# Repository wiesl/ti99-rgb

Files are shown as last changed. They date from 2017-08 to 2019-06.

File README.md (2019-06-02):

TMS9929A RGB Converter
======================

This RGB converter is based on this great project:
[TMS9929A RGB and Component adapter - A high resolution Component, RGB or SCART adapter for MSX and Colecovision](https://hackaday.io/project/13056-tms9929a-rgb-and-component-adapter).

It converts signals from a TMS9929 with correct colors to RGB.

See also this [thread](https://www.classic-computers.org.nz/forums/viewtopic.php?f=11&t=960) for more information.

Authors
=======

Original author: Copyright 2016: Alexis Kotlowy <256byteram@gmail.com>

Enhanced version: Copyright 2017: Gerhard Wiesinger <ti99@wiesinger.com>

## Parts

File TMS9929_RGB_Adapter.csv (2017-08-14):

Reference | Value | Footprint | Datasheet
U2 | XR8052 | SMD_Packages:SOIC-8-N
U3 | XR8052 | SMD_Packages:SOIC-8-N
R11 | 1k | Resistors_SMD:R_0805_HandSoldering
R14 | 2k | Resistors_SMD:R_0805_HandSoldering
R13 | 3.6k | Resistors_SMD:R_0805_HandSoldering
R22 | 1k | Resistors_SMD:R_0805_HandSoldering
R19 | 1k | Resistors_SMD:R_0805_HandSoldering
R20 | 1k | Resistors_SMD:R_0805_HandSoldering
R21 | 2k | Resistors_SMD:R_0805_HandSoldering
U1 | XR8052 | SMD_Packages:SOIC-8-N
R4 | 1k | Resistors_SMD:R_0805_HandSoldering
R6 | 2k | Resistors_SMD:R_0805_HandSoldering
R5 | 1.2k | Resistors_SMD:R_0805_HandSoldering
R7 | 1k | Resistors_SMD:R_0805_HandSoldering
R3 | 1k | Resistors_SMD:R_0805_HandSoldering
R1 | 1.2k | Resistors_SMD:R_0805_HandSoldering
R12 | 6.2k | Resistors_SMD:R_0805_HandSoldering
R15 | 9.1k | Resistors_SMD:R_0805_HandSoldering
R18 | 1k | Resistors_SMD:R_0805_HandSoldering
R16 | 1k | Resistors_SMD:R_0805_HandSoldering
R8 | 1k | Resistors_SMD:R_0805_HandSoldering
R10 | 1k | Resistors_SMD:R_0805_HandSoldering
R2 | 75R | Resistors_SMD:R_0805_HandSoldering
R9 | 75R | Resistors_SMD:R_0805_HandSoldering
R17 | 75R | Resistors_SMD:R_0805_HandSoldering
C3 | 47uF | Capacitors_Tantalum_SMD:TantalC_SizeB_EIA-3528_HandSoldering
C2 | 47uF | Capacitors_Tantalum_SMD:TantalC_SizeB_EIA-3528_HandSoldering
C1 | 47uF | Capacitors_Tantalum_SMD:TantalC_SizeB_EIA-3528_HandSoldering
P1 | CONN_01X06 | Pin_Headers:Pin_Header_Straight_1x06
U4 | 4066 | SMD_Packages:SOIC-14_N
U5 | LM1881 | SMD_Packages:SOIC-8-N
C6 | 100nF | Capacitors_SMD:C_0805_HandSoldering
C7 | 100nF | Capacitors_SMD:C_0805_HandSoldering
R23 | 680k | Resistors_SMD:R_0805_HandSoldering
C8 | 47uF | Capacitors_Tantalum_SMD:TantalC_SizeB_EIA-3528_HandSoldering
C9 | 100nF | Capacitors_SMD:C_0805_HandSoldering
C10 | 100nF | Capacitors_SMD:C_0805_HandSoldering
C11 | 100nF | Capacitors_SMD:C_0805_HandSoldering
C12 | 100nF | Capacitors_SMD:C_0805_HandSoldering
C13 | 100nF | Capacitors_SMD:C_0805_HandSoldering
R24 | 680R | Resistors_SMD:R_0805_HandSoldering
R25 | 82R | Resistors_SMD:R_0805_HandSoldering
P6 | CONN_01X01 | Connect:1pin
P7 | CONN_01X01 | Connect:1pin
P8 | CONN_01X01 | Connect:1pin
P9 | CONN_01X01 | Connect:1pin
P3 | SEL | Pin_Headers:Pin_Header_Straight_1x03
P4 | SEL | Pin_Headers:Pin_Header_Straight_1x03
P5 | SEL | Pin_Headers:Pin_Header_Straight_1x03
U6 | TL081 | SMD_Packages:SOIC-8-N
C14 | 10nF | Capacitors_SMD:C_0805_HandSoldering
C15 | 100nF | Capacitors_SMD:C_0805_HandSoldering
R28 | 10k | Resistors_SMD:R_0805_HandSoldering
R29 | 10k | Resistors_SMD:R_0805_HandSoldering
P2 | CONN_01X08 | Pin_Headers:Pin_Header_Straight_1x08
P10 | 12V | Pin_Headers:Pin_Header_Straight_1x01
R30 | 270R | Resistors_SMD:R_0805_HandSoldering
L1 | FERRITE | Resistors_SMD:R_1206_HandSoldering
R26 | 1k | Resistors_SMD:R_0805_HandSoldering

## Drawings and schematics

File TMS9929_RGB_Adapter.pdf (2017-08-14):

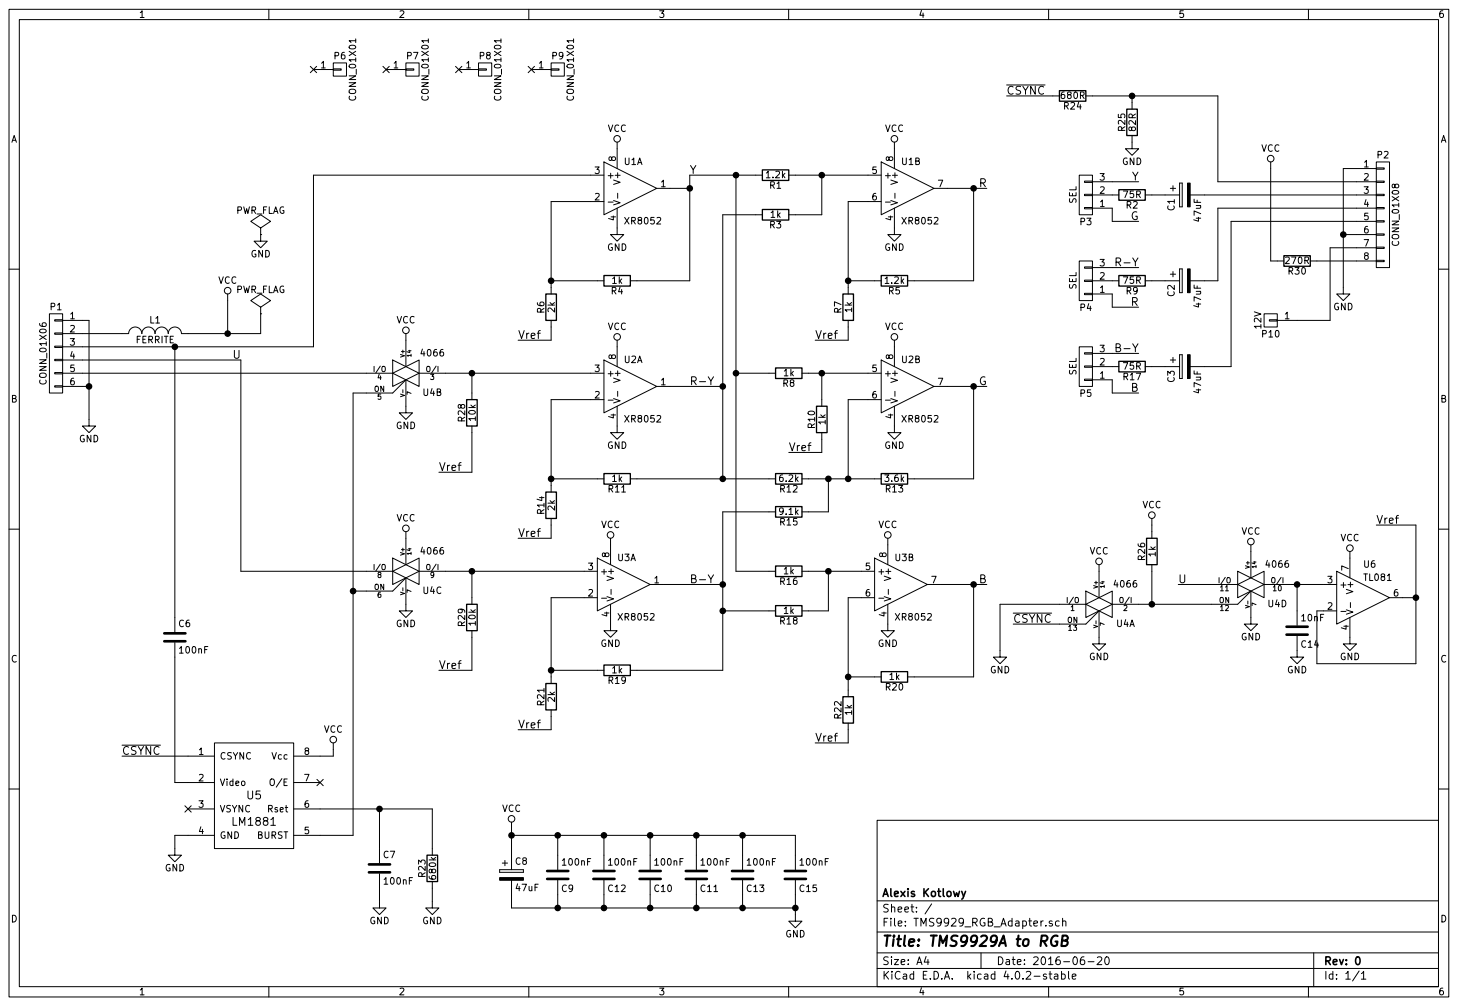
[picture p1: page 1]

Id: 1/1 Title: TMS9929A to RGB

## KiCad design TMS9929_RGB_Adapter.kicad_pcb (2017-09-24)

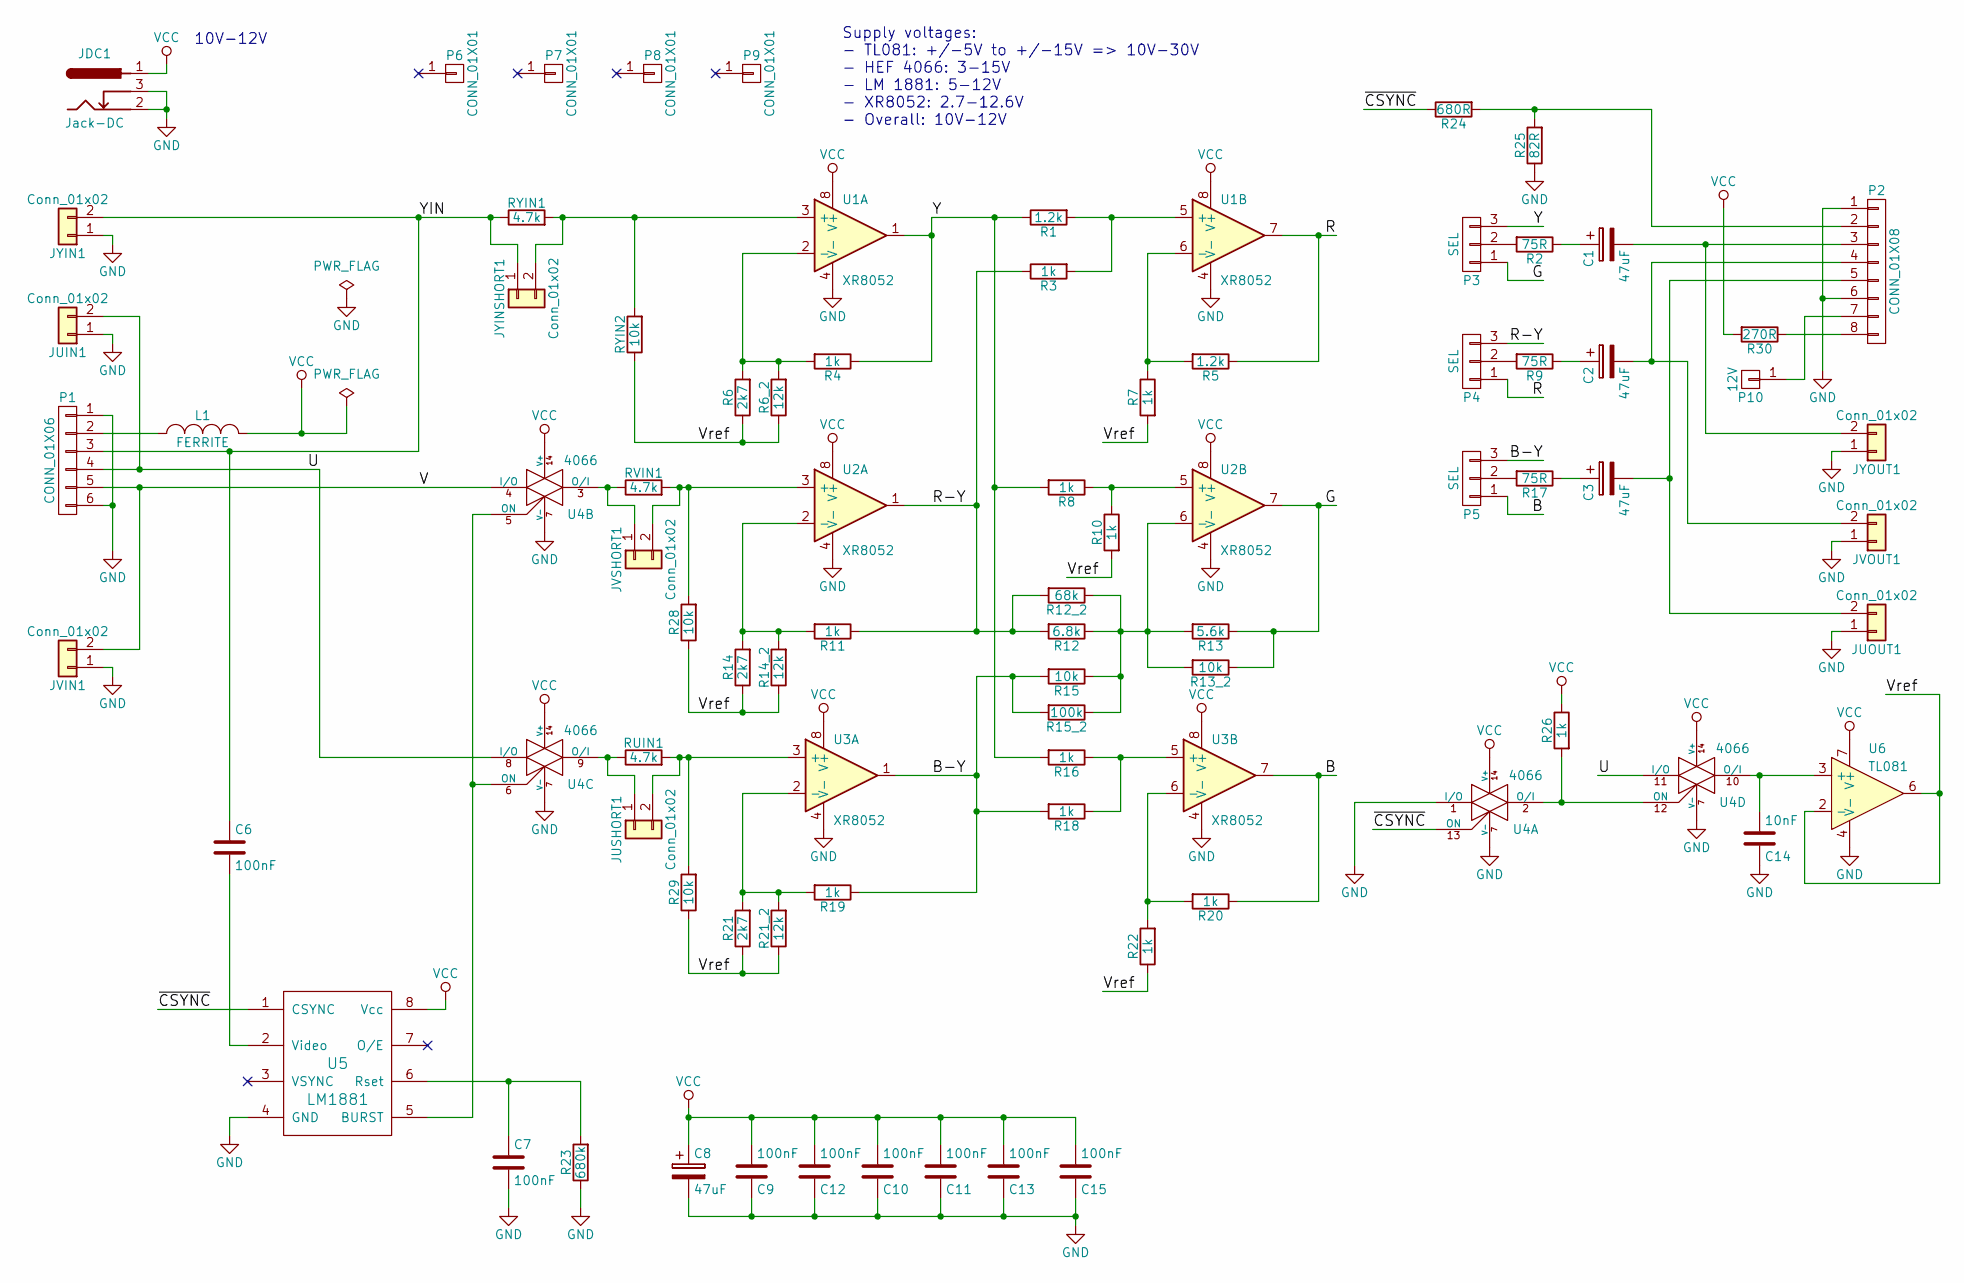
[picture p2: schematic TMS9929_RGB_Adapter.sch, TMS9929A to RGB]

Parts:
C1, C2, C3, C8: 47uF; TantalC_SizeB_EIA-3528_HandSoldering
C6, C7, C9, C10, C11, C12, C13, C15: 100nF; C_0805_HandSoldering
C14: 10nF; C_0805_HandSoldering
JDC1: Jack-DC; jack_2mm
JUIN1: Conn_01x02; rca_white
JUOUT1: Conn_01x02; rca_white
JUSHORT1: Conn_01x02; Pin_Header_Straight_1x02_Pitch2.54mm
JVIN1: Conn_01x02; rca_red
JVOUT1: Conn_01x02; rca_red
JVSHORT1: Conn_01x02; Pin_Header_Straight_1x02_Pitch2.54mm
JYIN1: Conn_01x02; rca_black
JYINSHORT1: Conn_01x02; Pin_Header_Straight_1x02_Pitch2.54mm
JYOUT1: Conn_01x02; rca_black
L1: FERRITE; R_1206_HandSoldering
P1: CONN_01X06; Pin_Header_Straight_1x06_Pitch2.54mm
P2: CONN_01X08; Pin_Header_Straight_1x08_Pitch2.54mm
P3, P4, P5: SEL; Pin_Header_Straight_1x03_Pitch2.54mm
P6, P7, P8, P9: CONN_01X01; 1pin
P10: 12V; Pin_Header_Straight_1x01
R1, R5: 1.2k; R_0805_HandSoldering
R2, R9, R17: 75R; R_0805_HandSoldering
R3, R4, R7, R8, R10, R11, R16, R18, R19, R20, R22, R26: 1k; R_0805_HandSoldering
R6, R14, R21: 2k7; R_0805_HandSoldering
R6_2, R14_2, R21_2: 12k; R_0805_HandSoldering
R12: 6.8k; R_0805_HandSoldering
R12_2: 68k; R_0805_HandSoldering
R13: 5.6k; R_0805_HandSoldering
R13_2, R15, R28, R29: 10k; R_0805_HandSoldering
R15_2: 100k; R_0805_HandSoldering
R23: 680k; R_0805_HandSoldering
R24: 680R; R_0805_HandSoldering
R25: 82R; R_0805_HandSoldering
R30: 270R; R_0805_HandSoldering
RUIN1: 4.7k; R_0805_HandSoldering
RVIN1: 4.7k; R_0805_HandSoldering
RYIN1: 4.7k; R_0805_HandSoldering
RYIN2: 10k; R_0805_HandSoldering
U1, U2, U3: XR8052; SOIC-8-N
U4: 4066; SOIC-14_N
U5: LM1881; SOIC-8-N
U6: TL081; SOIC-8-N

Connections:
/B: P5.1, R20.1, U3.7
/B-Y: P5.3, R15.2, R15_2.2, R18.2, R19.1, U3.1
/G: P3.1, R13.1, R13_2.1, U2.7
/R: P4.1, R5.1, U1.7
/R-Y: P4.3, R3.1, R11.1, R12.2, R12_2.2, U2.1
/U: JUIN1.2, P1.4, U4.8 (I/O), U4.11 (I/O)
/V: JVIN1.2, P1.5, U4.4 (I/O)
/Vref: R6.1, R6_2.1, R7.2, R10.2, R14.1, R14_2.1, R21.1, R21_2.1, R22.1, R28.1, R29.1, RYIN2.1, U6.2 (-), U6.6
/Y: P3.3, R1.1, R4.1, R8.2, R16.2, U1.1
/YIN: C6.1, JYIN1.2, JYINSHORT1.1, P1.3, RYIN1.1
/~CSYNC: R24.1, U4.13 (ON), U5.1 (CSYNC)
GND: C7.2, C8.2, C9.1, C10.1, C11.1, C12.1, C13.1, C14.1, C15.1, JDC1.2, JDC1.3, JUIN1.1, JUOUT1.1, JVIN1.1, JVOUT1.1, JYIN1.1, JYOUT1.1, P1.1, P1.6, P2.1, P2.6, R23.1, R25.1, U1.4 (V-), U2.4 (V-), U3.4 (V-), U4.1 (I/O), U4.7 (V-), U5.4 (GND), U6.4 (V-)
unnamed: C1.1, R2.1
unnamed: C1.2, JYOUT1.2, P2.3
unnamed: C2.1, R9.1
unnamed: C2.2, JVOUT1.2, P2.4
unnamed: C3.1, R17.1
unnamed: C3.2, JUOUT1.2, P2.5
unnamed: C6.2, U5.2 (Video)
unnamed: C7.1, R23.2, U5.6 (Rset)
unnamed: C14.2, U4.10 (O/I), U6.3 (+)
unnamed: JUSHORT1.1, RUIN1.1, U4.9 (O/I)
unnamed: JUSHORT1.2, R29.2, RUIN1.2, U3.3 (+)
unnamed: JVSHORT1.1, RVIN1.1, U4.3 (O/I)
unnamed: JVSHORT1.2, R28.2, RVIN1.2, U2.3 (+)
unnamed: JYINSHORT1.2, RYIN1.2, RYIN2.2, U1.3 (+)
unnamed: L1.1, P1.2
unnamed: P2.2, R24.2, R25.2
unnamed: P2.8, R30.1
unnamed: P3.2, R2.2
unnamed: P4.2, R9.2
unnamed: P5.2, R17.2
unnamed: P2.7, P10.1
unnamed: R1.2, R3.2, U1.5 (+)
unnamed: R4.2, R6.2, R6_2.2, U1.2 (-)
unnamed: R5.2, R7.1, U1.6 (-)
unnamed: R8.1, R10.1, U2.5 (+)
unnamed: R11.2, R14.2, R14_2.2, U2.2 (-)
unnamed: R12.1, R12_2.1, R13.2, R13_2.2, R15.1, R15_2.1, U2.6 (-)
unnamed: R16.1, R18.1, U3.5 (+)
unnamed: R19.2, R21.2, R21_2.2, U3.2 (-)
unnamed: R20.2, R22.2, U3.6 (-)
unnamed: R26.2, U4.2 (O/I), U4.12 (ON)
unnamed: U4.5 (ON), U4.6 (ON), U5.5 (BURST)
VCC: C8.1, C9.2, C10.2, C11.2, C12.2, C13.2, C15.2, JDC1.1, L1.2, R26.1, R30.2, U1.8 (V+), U2.8 (V+), U3.8 (V+), U4.14 (V+), U5.8 (Vcc), U6.7 (V+)

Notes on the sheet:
10V-12V
Supply voltages: - TL081: +/-5V to +/-15V => 10V-30V - HEF 4066: 3-15V - LM 1881: 5-12V - XR8052: 2.7-12.6V - Overall: 10V-12V

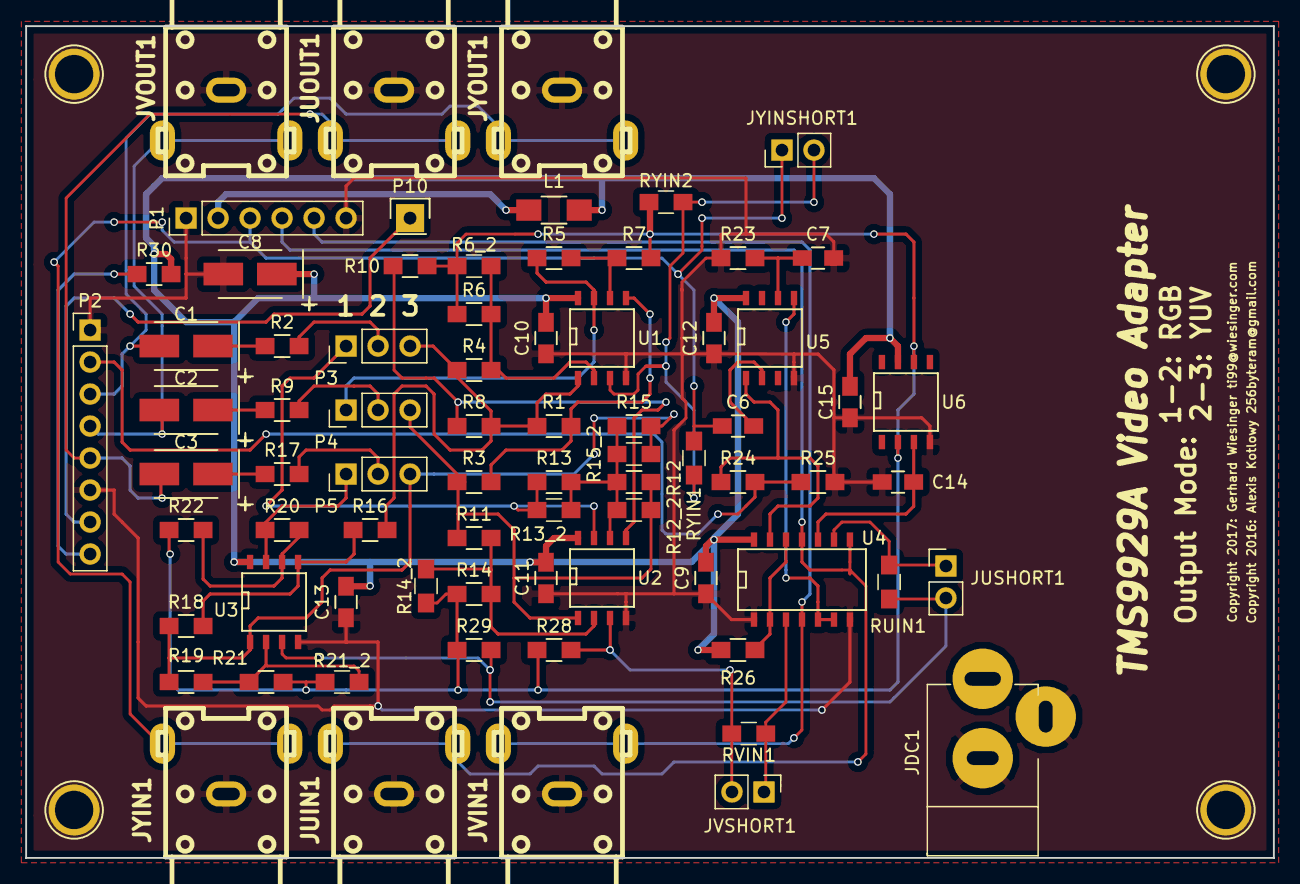
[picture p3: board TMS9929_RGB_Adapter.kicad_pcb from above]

Board: 2 copper layers, 99.1 x 66.0 mm, 79 parts (0 on the bottom side), 45 nets.

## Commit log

2017-08-14 Initial import
    [TMS9929_RGB_Adapter-B.Cu.gbr, TMS9929_RGB_Adapter-B.Mask.gbr, TMS9929_RGB_Adapter-B.SilkS.gbr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]
2017-09-17 Initial changes to new version, copyright, DRC, etc.
    [TMS9929_RGB_Adapter-B.Cu.gbl, TMS9929_RGB_Adapter-B.Cu.gbr, TMS9929_RGB_Adapter-B.Mask.gbr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]
2017-09-17 Updated libraries and removed old drill report file
2017-09-17 Updated schematic & PCB for added Cinch connectors as well as power supply connector and damping resistors/jumpers
    [TMS9929_RGB_Adapter-B.Cu.gbl, TMS9929_RGB_Adapter-B.Mask.gbs, TMS9929_RGB_Adapter-B.SilkS.gbo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]
2017-09-17 Corrected silkscreen with masks (moved it)
    [TMS9929_RGB_Adapter-B.Cu.gbl, TMS9929_RGB_Adapter-B.Mask.gbs, TMS9929_RGB_Adapter-B.SilkS.gbo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]
2017-09-19 Show copper layers
    [TMS9929_RGB_Adapter.kicad_pcb]
2017-09-19 Remove *.drl file
    [TMS9929_RGB_Adapter.drl]
2017-09-19 Smaller PCB cosmetics
    [TMS9929_RGB_Adapter-B.Cu.gbl, TMS9929_RGB_Adapter-B.Mask.gbs, TMS9929_RGB_Adapter-B.SilkS.gbo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]
2017-09-24 schematic: Added comments for power supply, moved capacitor at TL081 (cosmetics)
    [TMS9929_RGB_Adapter.sch]
2017-09-24 Added new resistors in parallel to existing ones to solder standard resistor values
    [TMS9929_RGB_Adapter-B.Cu.gbl, TMS9929_RGB_Adapter-B.Mask.gbs, TMS9929_RGB_Adapter-B.SilkS.gbo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]
